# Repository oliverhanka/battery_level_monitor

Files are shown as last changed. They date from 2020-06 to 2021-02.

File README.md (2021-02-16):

# Battery level monitor
The board is designed to measure the battery level (voltage) with an uC's ADC. The on-board voltage divider must be parameterized (R1 and R2) according to the uC's max ADC input as well as the battery's voltage level. The battery voltage may be higher then the ADC's Vcc.

The circuit includes two MOSFETs to cut-off the voltage divider in order to not drain the battery when not in use. The uC must pull up EN to activate the voltage divider. If EN is left floating (e.g., the uC is turned off or in deep-sleep), the on-board pulldown resistor cuts of the voltage divider.

## Parameterize voltage divider
Calculate the two resistors R1 and R2 to fit your application needs (e.g., use an [online calculator](http://www.ohmslawcalculator.com/voltage-divider-calculator)). Example:

| Battery | ADC input | R1 | R1 |
| --- | --- | --- | --- |
| 14V | 3.3V | 75k | 18k |

(resistor values adjusted to match common resistor series)

## Connectors / headers / solder jumper

| Connector | Purpose |
| --- | --- |
| J1 | to uC - (1) EN, (2) ADC, (3) GND |
| J2 | to battery - (1) Vbat, (2) GND |
| JP1 | bridge to enable voltage divider permanetly |

## Build

The board is hand solderable with some practise. Components are 0805 and SOT23 footprint.

### Schematic

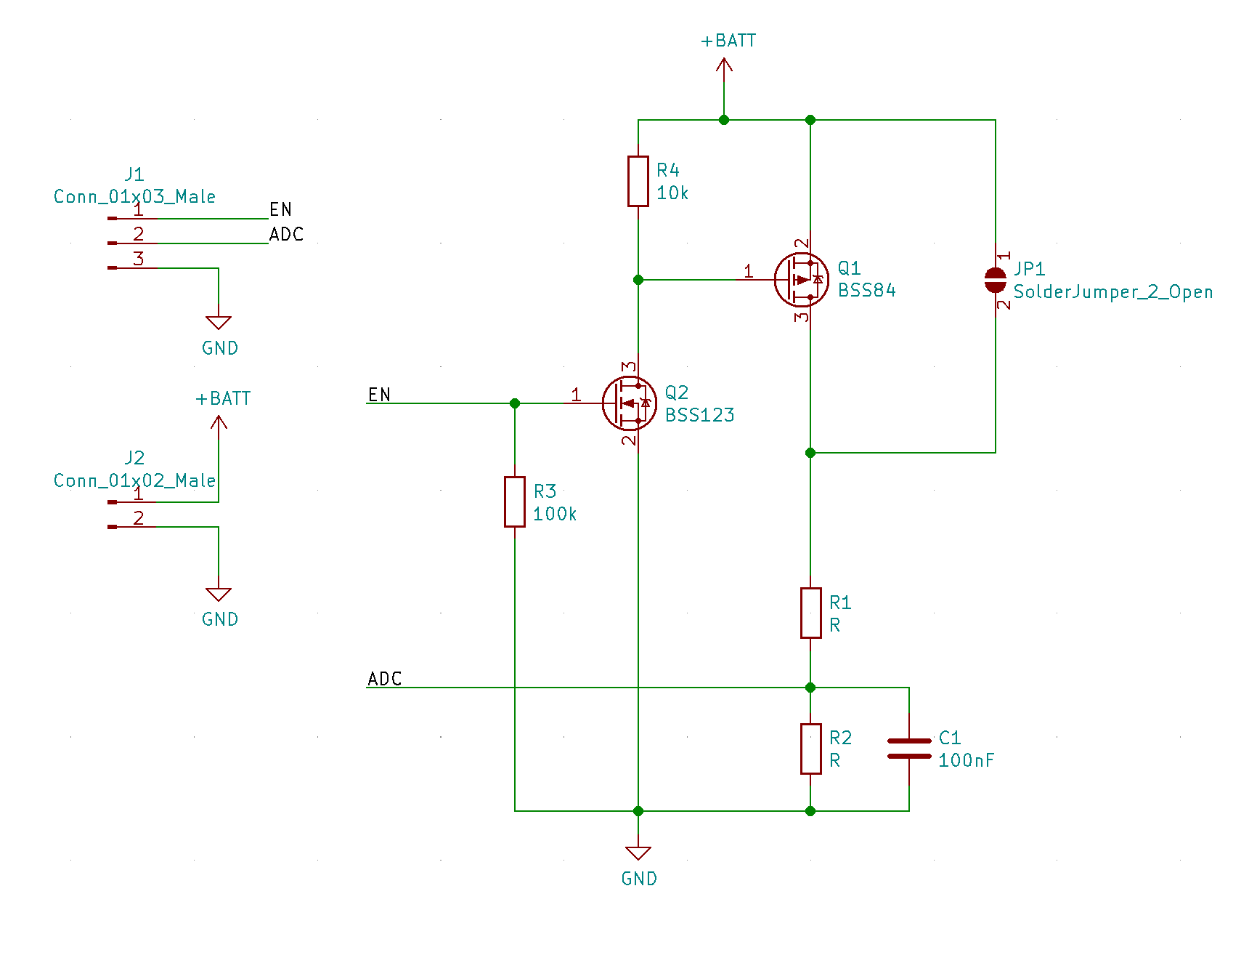
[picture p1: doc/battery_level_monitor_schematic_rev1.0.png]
Schematic


### Bill of materials (BOM)

| Designator | Manufacturer Part Number | Qty |
| --- | --- |	--- |
|J1 |	S3B-PH-SM4-TB(LF)(SN) |	1 |
|J2 |	S2B-PH-SM4-TB(LF)(SN) |	1 |
|R1 |	(must be calculated) 0805 |	1 |
|R2 |	(must be calculated) 0805 |	1 |
|R3 |	100k 0805|	1 |
|R4 |	10k 0805|	1 |
|C1 |	100nF 0805|	1 |
|Q1 |	BSS84 SOT23|	1 |
|Q2 |	BSS123 SOT23 |	1 |

### PCB Rendering
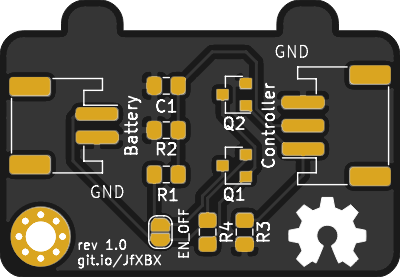
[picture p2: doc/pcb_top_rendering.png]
PCB front
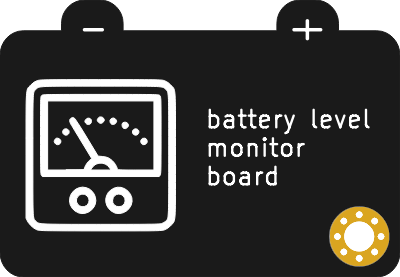
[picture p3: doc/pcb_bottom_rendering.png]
PCB back
 | 
------------ | -------------
frontside rev 1.0 | backside rev 1.0

### Order PCBs
You can create gerber files (KiCad -> Plot) and upload them to the PCB manufacturer of your choice. You can also use this preconfigured [PCBs.io link](https://PCBs.io/share/4o5we) which will earn me some royalties.

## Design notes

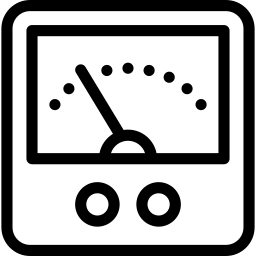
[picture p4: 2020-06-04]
ressources/voltmeter.png

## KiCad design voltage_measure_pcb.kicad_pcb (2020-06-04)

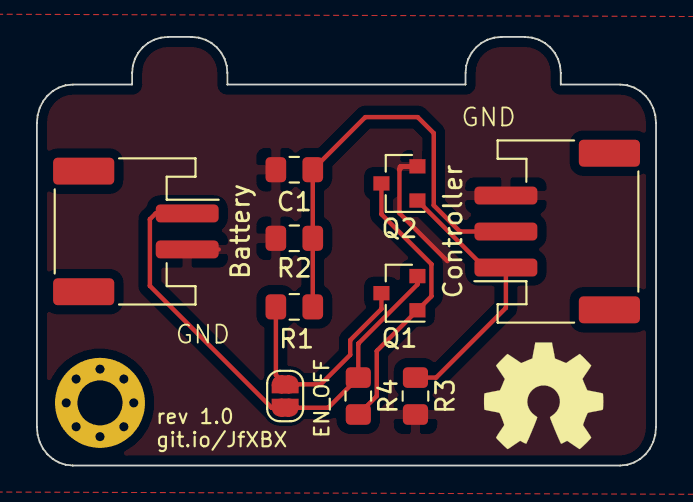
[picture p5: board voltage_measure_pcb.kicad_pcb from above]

Board: 2 copper layers, 34.4 x 23.8 mm, 10 parts (0 on the bottom side), 6 nets.

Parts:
Battery: Conn_01x02_Male; JST_PH_S2B-PH-SM4-TB_1x02-1MP_P2.00mm_Horizontal
C1: 100nF; C_0805_2012Metric_Pad1.15x1.40mm_HandSolder
Controller: Conn_01x03_Male; JST_PH_S3B-PH-SM4-TB_1x03-1MP_P2.00mm_Horizontal
EN_OFF: SolderJumper_2_Open; SolderJumper-2_P1.3mm_Open_RoundedPad1.0x1.5mm
Q1: BSS84; SOT-23
Q2: BSS123; SOT-23
R1, R2: R; R_0805_2012Metric_Pad1.15x1.40mm_HandSolder
R3: 100k; R_0805_2012Metric_Pad1.15x1.40mm_HandSolder
R4: 10k; R_0805_2012Metric_Pad1.15x1.40mm_HandSolder

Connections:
+BATT: Battery.1, EN_OFF.1, Q1.2, R4.1
/ADC: C1.1, Controller.2, R1.2, R2.1
/EN: Controller.1, Q2.1, R3.1
GND: Battery.2, C1.2, Controller.3, Q2.2, R2.2, R3.2
unnamed: EN_OFF.2, Q1.3, R1.1
unnamed: Q1.1, Q2.3, R4.2

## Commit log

2020-06-04 initial commit - rev 1.0
    [voltage_measure_pcb.kicad_pcb, voltage_measure_pcb.sch]
2020-06-04 missing EN wire fixed
    [voltage_measure_pcb.sch]
